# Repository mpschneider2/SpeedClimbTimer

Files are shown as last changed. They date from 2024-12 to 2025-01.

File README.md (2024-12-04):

# SpeedClimbTimer

How it should work: holding button 1 for 5 seconds sets the clock to 0, releasing the long hold (onebutton) after the 5 seconds starts the timer
Hitting button 2 should pause the timer and it should blink slowly if not a high score, strobe if a high score. Maybe add a buzzer

it should continue blinking until button 1 is pressed/clicked, where it should then show the high score in solid light.

And a quadruple click should erase the last record if it was made in the same session in which it was plugged in.

and every time a new record is made, in needs to be stored in the EEPROM

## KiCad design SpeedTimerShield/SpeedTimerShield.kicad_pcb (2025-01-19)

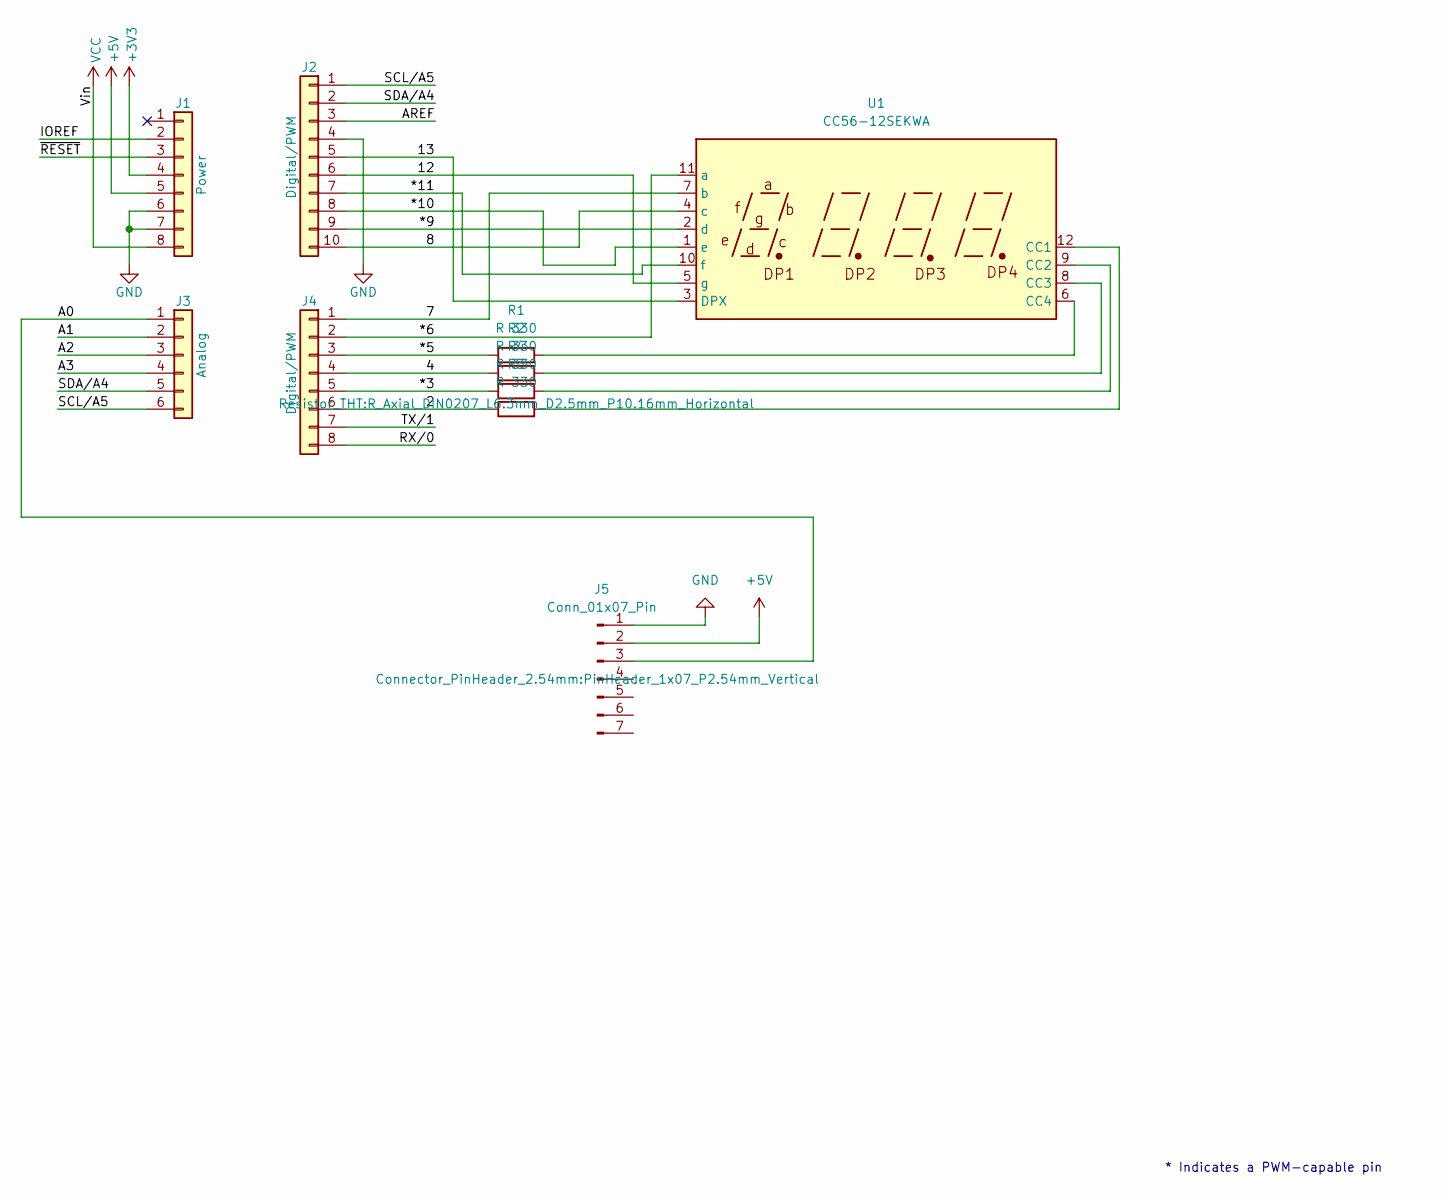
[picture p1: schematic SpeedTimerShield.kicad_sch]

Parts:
J1: Power; PinSocket_1x08_P2.54mm_Vertical
J2: Digital/PWM; PinSocket_1x10_P2.54mm_Vertical
J3: Analog; PinSocket_1x06_P2.54mm_Vertical
J4: Digital/PWM; PinSocket_1x08_P2.54mm_Vertical
J5: Conn_01x07_Pin; PinHeader_1x07_P2.54mm_Vertical
R1, R2, R3, R4: R 330; R_Axial_DIN0207_L6.3mm_D2.5mm_P10.16mm_Horizontal
U1: CC56-12SEKWA; CA56-12SEKWA

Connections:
+3V3: J1.4
+5V: J1.5, J5.2
/2: J4.6, R3.1
/4: J4.4, R2.1
/7: J4.1, U1.7 (b)
/8: J2.10, U1.4 (c)
/12: J2.6, U1.5 (g)
/13: J2.5, U1.3 (DPX)
/*3: J4.5, R4.1
/*5: J4.3, R1.1
/*6: J4.2, U1.11 (a)
/*9: J2.9, U1.2 (d)
/*10: J2.8, U1.1 (e)
/*11: J2.7, U1.10 (f)
/A0: J3.1, J5.3
/A1: J3.2
/A2: J3.3
/A3: J3.4
/AREF: J2.3
/IOREF: J1.2
/RX/0: J4.8
/SCL/A5: J2.1, J3.6
/SDA/A4: J2.2, J3.5
/TX/1: J4.7
/~RESET: J1.3
GND: J1.6, J1.7, J2.4, J5.1
unnamed: R3.2, U1.12 (CC1)
unnamed: R4.2, U1.9 (CC2)
unnamed: R2.2, U1.8 (CC3)
unnamed: R1.2, U1.6 (CC4)
VCC: J1.8

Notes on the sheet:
* Indicates a PWM-capable pin

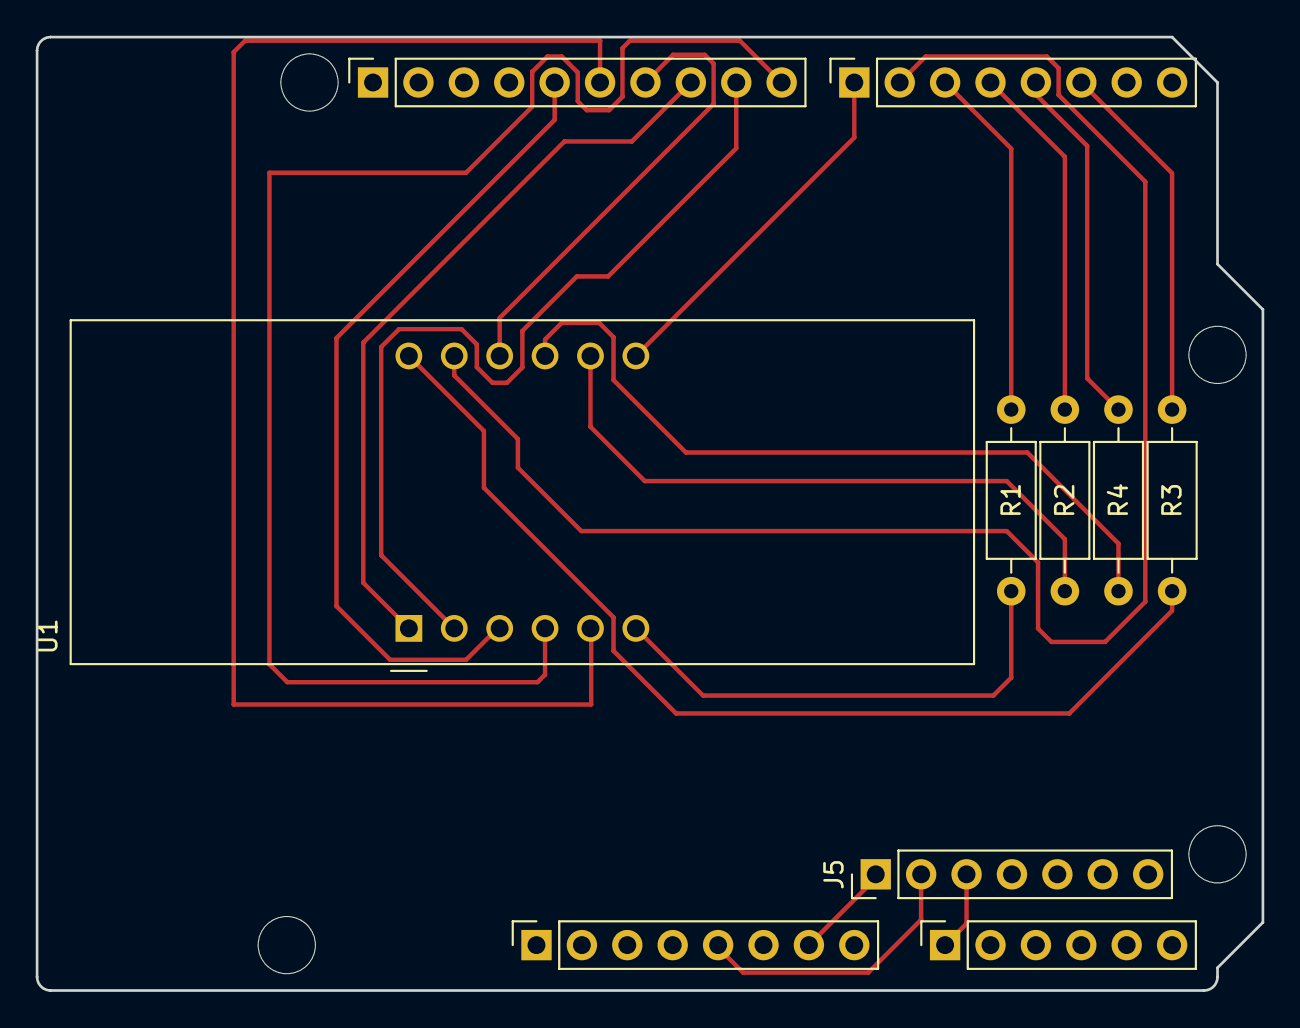
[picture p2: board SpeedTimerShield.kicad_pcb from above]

Board: 2 copper layers, 68.6 x 53.3 mm, 14 parts (0 on the bottom side), 21 nets.

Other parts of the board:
MH1, MH2, MH3, MH4: MountingHole_3.2mm

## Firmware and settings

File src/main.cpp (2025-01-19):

#include "SevSeg.h"
#include "OneButton.h"
SevSeg sevseg; //Initiate a seven segment controller object

unsigned long timerStart = 0;
int timer = 0;
int highScore = 9999;

int Button2 = A0;

int DisplayState = 0;
//0 is highscore, 1 is 00:00, 2 is timer, 3 is blinking time at end, 4 is blinking time NEW HIGH SCORE

OneButton Button1 = OneButton (
    A1,
    true,
    true
);

unsigned long ButtonHitMillis = 0;

void setup() {
    byte numDigits = 4;  
    // byte digitPins[] = {2, 3, 4, 5}; //Original Wiring
    byte digitPins[] = {7, 4, 3, 13}; //Custom Shield Wiring
    // byte segmentPins[] = {6, 7, 8, 9, 10, 11, 12, 13}; //Original Wiring
    byte segmentPins[] = {6, 2, 11, 9, 8, 5, 12, 10}; //Custom Shield Wiring
    bool resistorsOnSegments = 0;

    pinMode(Button2, INPUT_PULLUP);

    // variable above indicates that 4 resistors were placed on the digit pins.
    // set variable to 1 if you want to use 8 resistors on the segment pins.
    sevseg.begin(COMMON_CATHODE, numDigits, digitPins, segmentPins, resistorsOnSegments);
    sevseg.setBrightness(90);

    Button1.attachPress([]() {
        if (DisplayState != 2) DisplayState = 0;
    });

    Button1.attachLongPressStart([]() {
        DisplayState = 1;
    });

    Button1.attachLongPressStop([]() {
        DisplayState = 2;
        timerStart = millis();
    });

    Button1.setPressMs(3000);
}

void runTimer() {
    timer = (millis()-timerStart)/10;
}

void loop() {
    if (DisplayState==2) {
        runTimer();
        sevseg.setNumber(timer, 2);
    } else if (DisplayState==3) {
        if (timer <= highScore) {
            highScore = timer;

            if ((millis()-ButtonHitMillis)/10%30 < 20) {
                sevseg.setNumber(timer, 2);
            } else {
                sevseg.blank();
            }

        } else {
            if ((millis()-ButtonHitMillis)/10%150 < 125) {
                sevseg.setNumber(timer, 2);
            } else {
                sevseg.blank();
            }
        }
        
    } else if (DisplayState == 0) {
        sevseg.setNumber(highScore, 2);
    } else if (DisplayState == 1) {
        timer = 0;
        sevseg.setNumber(timer, 2);
    }

    sevseg.refreshDisplay(); // Must run repeatedly

    if (digitalRead(Button2)==HIGH) {
        if (DisplayState==2) {
            DisplayState = 3;
            ButtonHitMillis = millis();
        }
    }

    Button1.tick();
}
